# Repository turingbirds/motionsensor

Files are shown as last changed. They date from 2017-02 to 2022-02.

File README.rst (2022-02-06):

motionsensor
============

Microwave doppler effect motion sensor

Features
--------

- USB-powered (150 mA)
- Wakes up host computer on alarm (USB remote wakeup)
- Standalone operation (no PC or USB host required)
- Live velocity (IF) monitoring via USB audio stream to PC
- Automatic gain control
- Data logging
- Driverless operation: tested on Windows XP, Windows 7, Ubuntu GNU/Linux 14.04

..	![Image](https://raw.githubusercontent.com/turingbirds/con-pcb-slot/master/fig1.jpg)

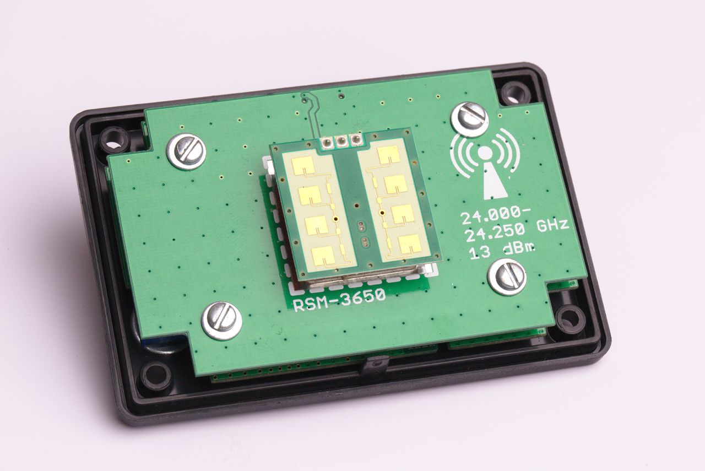
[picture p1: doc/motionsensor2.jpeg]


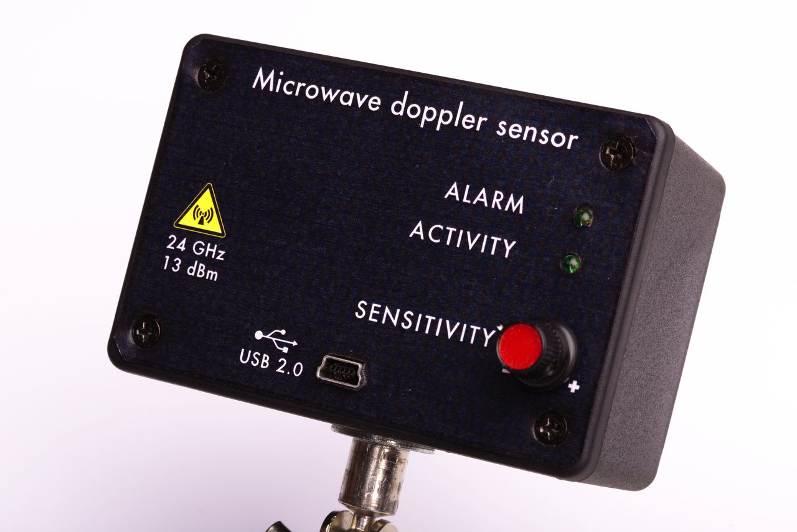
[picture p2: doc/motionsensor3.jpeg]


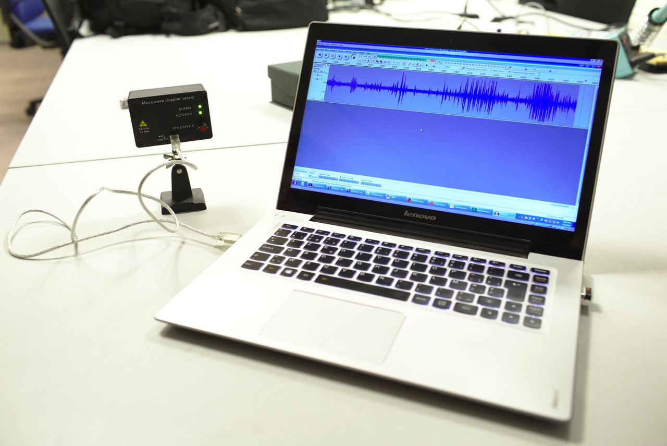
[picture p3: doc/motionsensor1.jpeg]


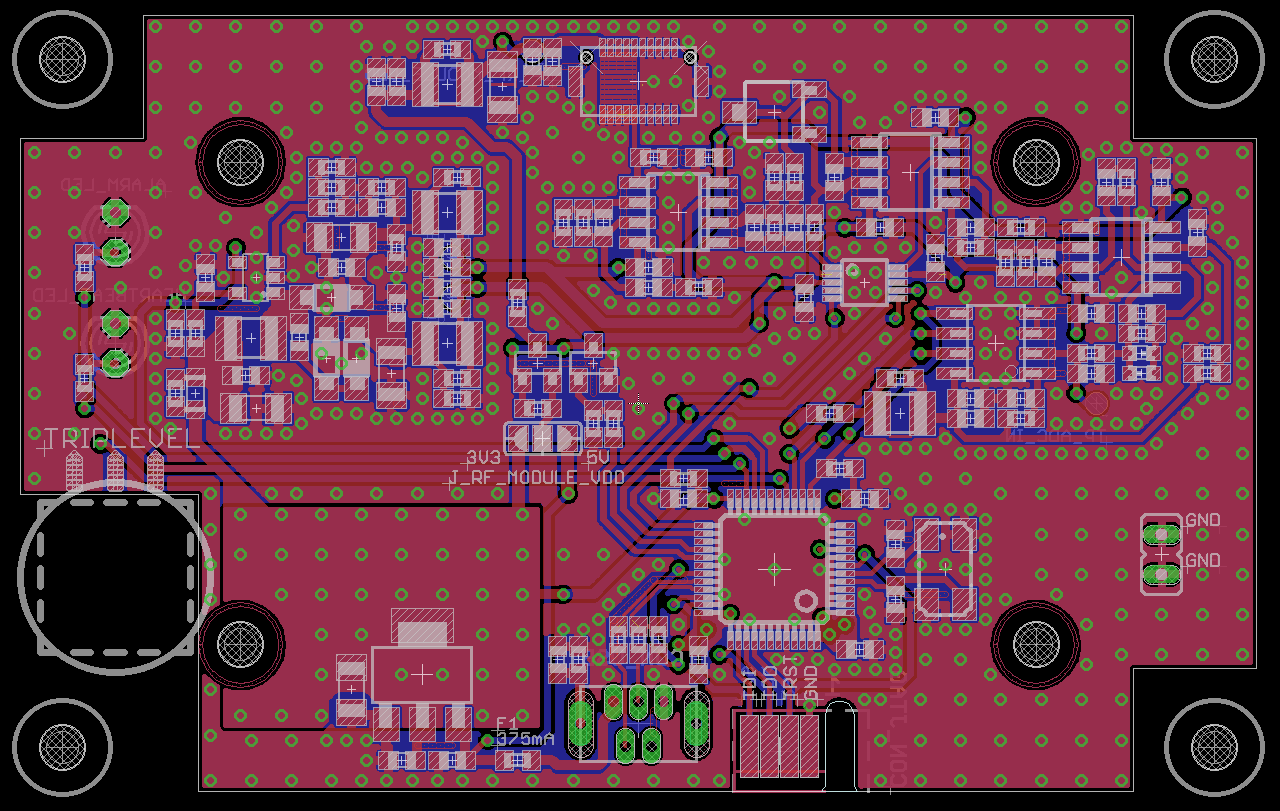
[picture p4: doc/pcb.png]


|

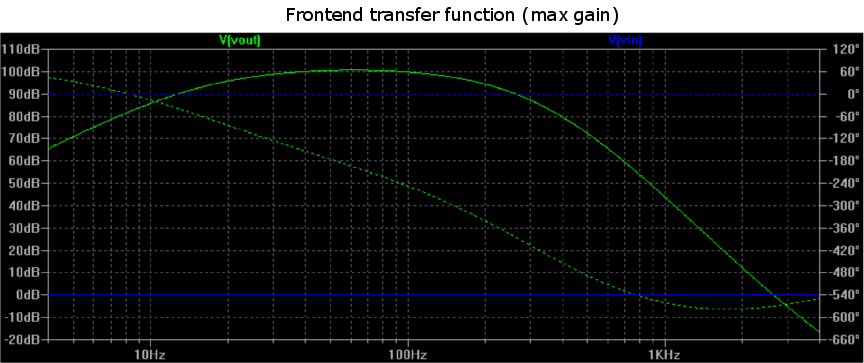
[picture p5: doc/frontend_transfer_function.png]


|

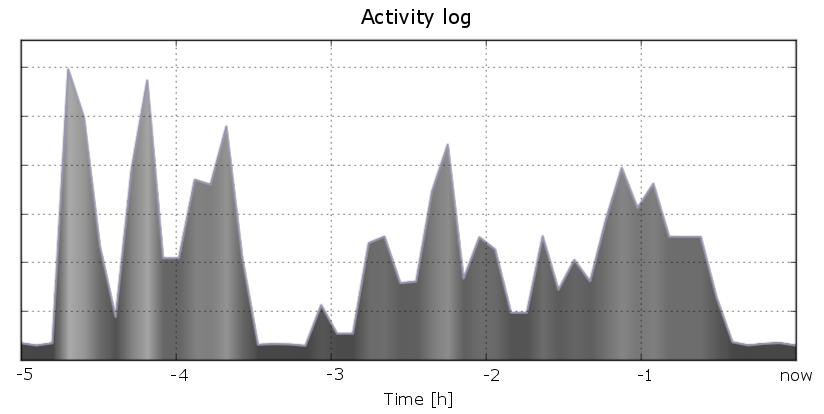
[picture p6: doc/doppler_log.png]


|

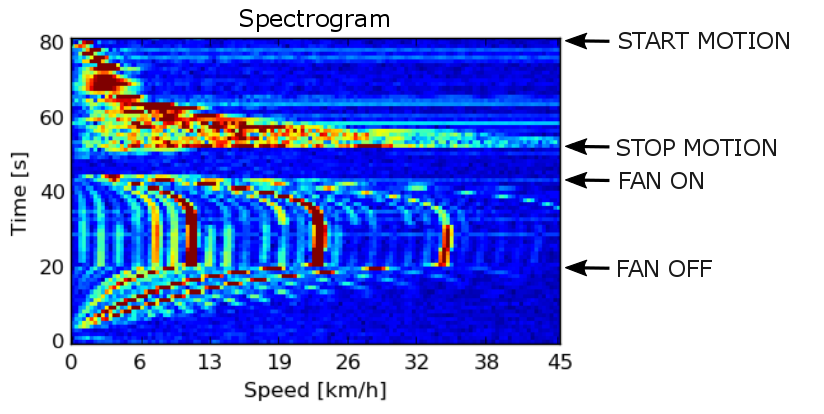
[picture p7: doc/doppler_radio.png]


.. class:: center

All photos thanks to `Dennis van Zuijlekom <https://www.flickr.com/photos/dvanzuijlekom/>`_ at `Hack42 <http://www.hack42.nl>`_!

User guide
==========

Overview
--------

The device is based around a compact radar module. Radar waves penetrate glass and other materials, allowing the device to operate completely hidden from sight, unlike traditional passive infrared (PIR) motion detectors. The principle of operation for motion detection is the doppler effect. The module acts simultaneously as a sender and receiver of radar waves. Part of the emitted waves are reflected in the environment and fall back onto the sensor. If, meanwhile, an object in the environment has a motion component normal to the sensor, a doppler shift will be introduced in the reflected radio waves, proportional to the velocity of the object. The resulting frequency change (between emitted and received frequency) is demodulated by the module and output as a signal in the audio band. The rest of the device amplifies this signal and digitises it for further processing with the microcontroller and (optionally) relay to a connected USB host as an audio stream.

Many radar modules are commercially available for less than $10. This repository contains all the information necessary to build a complete USB/standalone motion detector based on such a module.

USB operation
-------------

The device uses a USB Interface Association Descriptor [1]_ to identify itself as (1) a standard HID-compliant mouse and (2) a standard USB streaming audio device. Only the HID can wake the computer.

Standalone operation
--------------------

The motion sensor does not require a USB host and can operate in standalone mode. For independent operation, supply power (4.5..14 V) via the USB GND and Vcc terminals.

When the alarm is raised, the USB D- line will be driven to +3.3V for at least 10 ms, after which it will return to a floating condition. The output impedance is at least 22 Ω due to the USB series resistor. If this line is used to drive external devices, it is advised to add a modest pull-down resistor (e.g. 4k7).

Host audio
==========

Linux
-----

In case of conflicts, remove interfering kernel drivers:

::

	sudo rmmod snd_usb_audio
	sudo rmmod snd_usbmidi_lib

Set volume levels and such:

::

	alsamixer

Find the motion sensor device:

::

	arecord -l

*Recording from the device:*

::

	arecord -f S16_LE -r 8000 -t raw -v -D hw:1,0 > foo.pcm

*Listening to the device:* This assumes that you are using pulseaudio.

::

	pactl load-module module-loopback latency_msec=1	

Windows XP
----------

*Recording from the device:* native, select "Microwave Doppler Sensor" as audio source

*Listening to the device:* Download "Virtual Audio Cable" [2]_ and use the "Audio Repeater" tool. Lag is at least 50 ms.

Windows 7
---------

*Recording from the device:* native

*Listening to the device:* native. Use "Listen to device" under [taskbar speaker icon] → Recording devices → Microwave Doppler Sensor → Properties → Listen → Listen to this device.

Host power management
=====================

N.B. USB wake needs to be enabled in BIOS

Linux
-----

Suspend using:

::

	pm-suspend

Find device in tree:

::

	grep -r Microwave /sys/devices/pci0000\:00/

In the ``power`` directory of the device, you'll find a file called ``wakeup``. Write "enabled" to this file, e.g.:

::

	echo "enabled" > /sys/devices/pci0000:00/0000:00:14.0/usb2/2-2/power/wakeup

Make sure to enable upstream hubs as well.

N.B. Add the commands in this section to ``/etc/rc.local`` to enable the wake-from-standby feature on boot.

Windows
-------

Enable "Allow device to wake computer from suspend" in the device manager properties of the HID-compatible mouse that is a part of the Microwave Doppler Sensor.

Developer's guide
=================

Frontend
--------

The frontend consists of a high-gain low-noise amplifier chain that is built using three dual op-amp ICs. The maximum theoretical voltage gain is 1.3·10\ :sup:`5` (100 dB). An 8-bit digital potentiometer after the second gain stage is configured as an attenuator and acts as gain control, with a dynamical range of 30 dB. The complete analog front-end is powered by a ±5V bipolar rail that is generated by an on-board boost converter. After amplification and filtering the signal is offered to a 12-bit ADC running at an 8 kHz sampling rate and 3.3 V reference voltage.

Data acquisition and USB communication is performed by an STM32F103 microcontroller. When connected to a USB host, the digital potentiometer setlevel is controlled by the volume setlevel of the device. When the volume is set to 100%, automatic gain control (AGC) is enabled. When not connected to USB, the potentiometer is set to a fixed value so that the frontend gain is high.

N.B. the AGC aliasing filter should be designed for one bit of noise at half the sampling rate, i.e. max. 0.81 mV @ 4 kHz (3.3 V across 12 bits = 0.81 mV/bit)

Firmware notes
--------------

For volume scale (how to map bits to decibels), see e.g. [3]_.

Schematic
---------

`Schematic (.pdf) <doc/motionsensor_schematic.pdf>`_

PCB
---

All discrete components are 0603.

- Dimensions: 78 x 49 mm
- Layers: 4 (two inner ground planes)
- Thickness: 1.2 mm

Enclosure and mounting
----------------------

Vertical cross-section:

::

	----USB/USER INTERFACE----
	- 5 mm plastic inserts (1.0 mm margin)
	- 1.2 mm main PCB
	- 5 mm bus
	- 1.2 mm shield PCB
	- 0.2 mm washer
	----DOPPLER UNIT----
	Total: 12 mm

Screw length: 12 mm
Screw diameter: 2.5 mm

N.B. Doppler module is <7 mm

Bill of materials
-----------------

`Bill of materials (.csv) <doc/bill_of_materials.csv>`_

References
==========

.. [1] USB Complete Fourth Edition: The Developer's Guide (4th edition). Jan Axelson, publisher: Lakeview Research. June 1, 2009
.. [2] `Virtual Audio Cable \<http://software.muzychenko.net/eng/vac.htm\> <http://software.muzychenko.net/eng/vac.htm>`_
.. [3] `USB audio device volume scale \<https://msdn.microsoft.com/en-us/library/windows/hardware/ff537309\> <https://msdn.microsoft.com/en-us/library/windows/hardware/ff537309(v=vs.85).aspx>`_

License
=======

`Open source hardware <https://www.oshwa.org/>`_ is hardware for which the design is made publicly available, so that anyone can study, modify, distribute, make, and sell the design or hardware based on that design, subject to the following license conditions.

Hardware licensed under the *CERN Open Hardware Licence Version 2 - Weakly Reciprocal,* a copy of which is included in this repository at `cern_ohl_w_v2.txt <https://github.com/turingbirds/motionsensor/blob/master/cern_ohl_w_v2.txt>`_.

Software licensed under the *Apache License 2.0,* a copy of which is included at `apache_license_2.0.txt <https://github.com/turingbirds/motionsensor/blob/master/apache_license_2.0.txt>`_.

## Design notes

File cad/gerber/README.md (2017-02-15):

    Top Layer: pcbname.GTL
    Inner Layer: pcbname.GL2(for 4 layer)
    Inner Layer: pcbname.GL3(for 4 layer)
    Bottom Layer: pcbname.GBL
    Solder Mask Top: pcbname.GTS
    Solder Mask Bottom: pcbname.GBS
    Silk Top: pcbname.GTO
    Silk Bottom: pcbname.GBO
    Solder paste top: pcbname.GTP
    Solder paste bottom: pcbname.GBP
    Drill Drawing: pcbname.TXT
    Board Outline + milling (important for USB connector slots): pcbname.GML/GKO

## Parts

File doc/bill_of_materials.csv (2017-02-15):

Qty | Identifier | Description | Value | Package | Mouser #
 |  | RESISTOR | NOT INSTALLED | 0603
2 | R38, R44 | RESISTOR | 0 | 0603
3 | R7, R36, R49 | RESISTOR | 10 | 0603
2 | R27, R29 | RESISTOR | 22 | 0603
7 | R8, R23, R28, R30, R32, R35, R47 | RESISTOR | 100 | 0603
2 | R10, R13 | RESISTOR | 1k | 0603
7 | R5, R31, R33, R34, R43, R45, R48 | RESISTOR | 1k5 | 0603
13 | R1, R2, R3, R4, R11, R14, R15, R17, R20, R24, R26, R37, R40 | RESISTOR | 10k | 0603
1 | R41 | RESISTOR | 3k3 | 0603
1 | R39 | RESISTOR | 47k | 0603
2 | R18, R22 | RESISTOR | 100k | 0603
 | C5 | CAPACITOR | NOT INSTALLED | 0603
2 | C18, C19 | CAPACITOR | 22p | 0603
1 | C36 | CAPACITOR | 470p | 0603
3 | C11, C12, C13, | CAPACITOR | 4n7 | 0603
27 | C9, C10, C14, C16, C17, C20, C21, C22, C24, C25, C26, C27, C28, C29, C31, C33, C34, C35, C37, C38, C42, C43, C46, C47, C48, C50, C51 | CAPACITOR | 47n | 0603
5 | C5, C6, C44, C45, C52 | CAPACITOR | 470n | 0603
3 | C7, C8, C15, | CAPACITOR | 1u | 0603
4 | C23, C30, C39, C40 | CAPACITOR | 10u | 1206 | 581-TCJA106M16R200
5 | L1 | INDUCTOR | 47u/11MHz/2.5R/35mA | 0603 | 963-LBMF1608T470K
1 | L2 | INDUCTOR | 47u/11MHz/2.14R/330mA | 1210 | 815-AISC-1210H-470K
2 | ALARM_LED, HEARTBEAT_LED | LED | GREEN THROUGH-HOLE | 3 mm
2 | D2, D4 | LED | INFRARED 1.6 V | 0603 | 604-APT1608F3C
3 | D5, D6, D7 | DIODE | MBR0520 | SOD-123 | 512-MBR0520L
1 | Q1 | N-CHANNEL MOSFET | BF170 | SOT-23
1 | Q2 | P-CHANNEL MOSFET | NDS0605 | SOT-23
1 | IC1 | IC | AD5290-10k | MSOP-10 | 584-AD5290YRMZ10
1 | U$1 | IC | LM27313 | TSOP-5 | 926-LM27313XMF/NOPB
2 | IC2, IC3 | IC | LM324D | SOIC-14 | 595-LM324ADR
1 | IC5 | IC | LM1117 | SOT-232 | 926-LM1117MPX3.3NOPB
1 | IC4 | IC | STM32F103 | LQFP-48 | 511-STM32F103CBT6
1 | F1 | FUSE | 375mA | 0603 | 581-F0603E0R37FSTR
1 | X1 | XTAL | 8 MHz | CTS406 (5 x 3.2 mm) | 815-ABM3B-8.0-B2-T
1 |  | POTENTIOMETER | 5k LINEAR | PANEL MOUNT | 652-3310P-101-502L | Wiper resistance not critical; can also use 10k
1 |  | POTENTIOMETER KNOB | RED |  | 450-0125 | For black version: 450-0125
1 | R12 | POTENTIOMETER | 100k LINEAR | 3223 SMD
1 | CONN_USB | CONN | USB-MINI | VERTICAL | 538-500075-0517
1 | CONN_SENSOR_ | CONN | HIROSE HEADERS | 20 way, height: 5 mm | 798-DF125020DP0.5V86
1 | CONN_SENSOR | CONN | HIROSE RECEPTACLE | 20 way, height: 5 mm | 798-DF12-20DS-0.5V86
1 |  | ENCLOSURE | HAMMOND | 1591XXLSBK (2.4 x 2.2 x 1.4 inch) | 546-1591XXLSBK |  | 546-1591XXLSBK
4 |  | STANDOFFS | M2.5; 5 mm |  | 761-M0504-25-AL
4 |  | SCREWS | M2.5; 12 mm |  | 534-29304
4 |  | WASHERS | M2.5

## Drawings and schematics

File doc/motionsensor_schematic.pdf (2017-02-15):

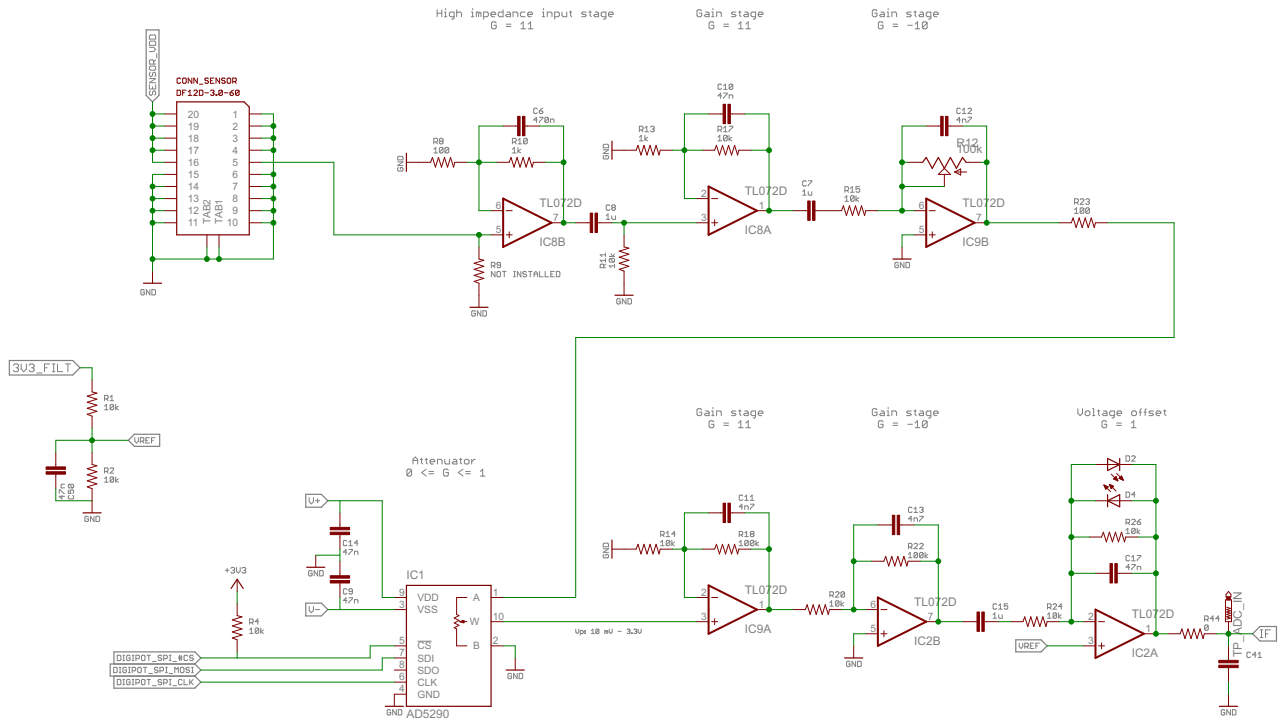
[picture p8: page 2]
100k ¹²³456789 11; TAB¹ TAB²; VDD 9; VSS 3; GND 4; SDI 7; SDO 8; 2 CLK 6; TP_ADC_IN R12

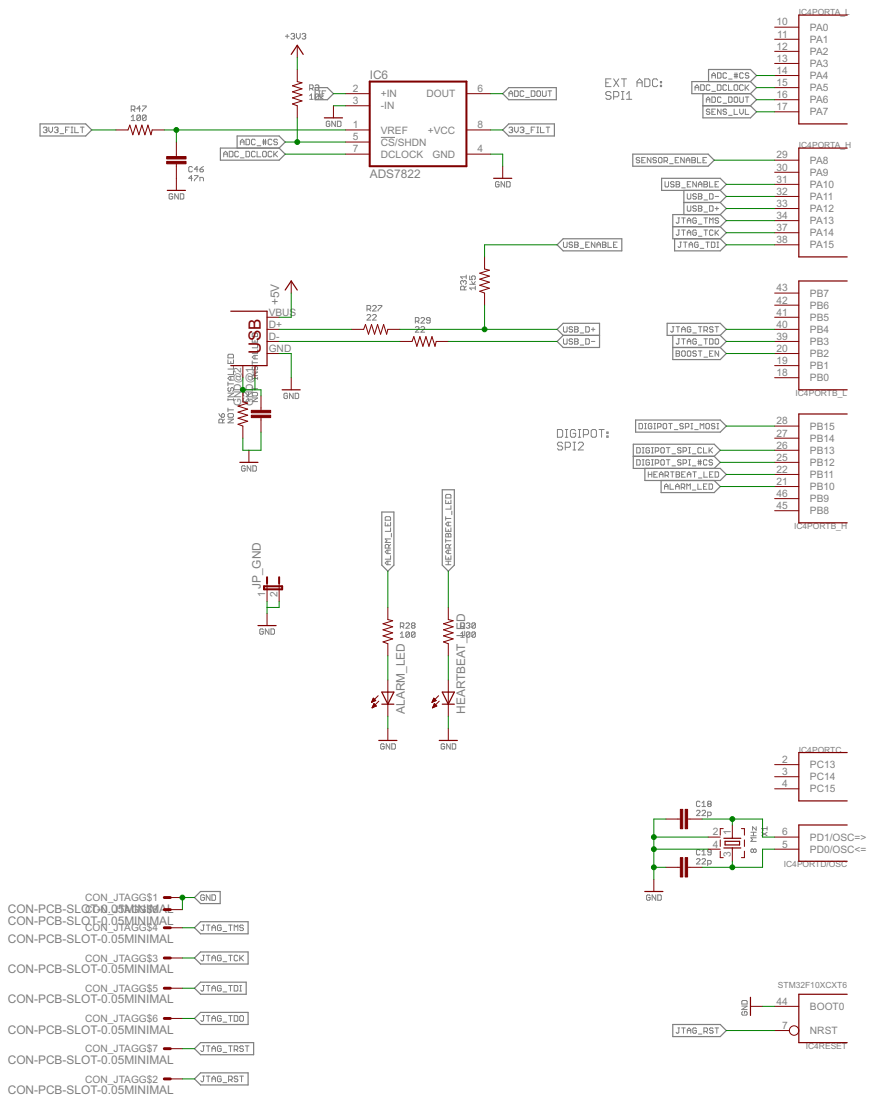
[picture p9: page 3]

+5V ADS7822 CON-PCB-SLOT-0.05MINIMAL CON-PCB-SLOT-0.05MINIMAL CON-PCB-SLOT-0.05MINIMAL CON-PCB-SLOT-0.05MINIMAL CON-PCB-SLOT-0.05MINIMAL CON-PCB-SLOT-0.05MINIMAL CON-PCB-SLOT-0.05MINIMAL CON-PCB-SLOT-0.05MINIMAL PA0 10 PA1 11 PA2 12 PA3 13 PA4 14 PA5 15 PA6 16 PA7 17 IC4PORTA_L PA8 29 PA9 30 PA10 31 PA11 32 PA12 33 PA13 34 PA14 37 PA15 38 IC4PORTA_H PB0 18 PB1 19 PB2 20 PB3 39 PB4 40 PB5 41 PB6 42 PB7 43 IC4PORTB_L PB8 45 PB9 46 PB10 21 PB11 22 PB12 25 PB13 26 PB14 27 PB15 28 IC4PORTB_H PC13 2 PC14 3 PC15 4 IC4PORTC PD0/OSC<= 5 PD1/OSC=> 6IC4PORTD/OSC NRST 7 BOOT0 44STM32F10XCXT6 IC4RESET 3 1 42 ALARM_LED HEARTBEAT_LED D+D- VBUS GND GND@1 GND@2 IC6+IN 2 -IN 3 VREF 1 DCLOCK 7 CS/SHDN 5 DOUT 6 +VCC 8 GND 4 CON_JTAGG$1 CON_JTAGG$8 CON_JTAGG$2 CON_JTAGG$3 CON_JTAGG$4 CON_JTAGG$5 CON_JTAGG$6 CON_JTAGG$7 JP_GND 12 USB

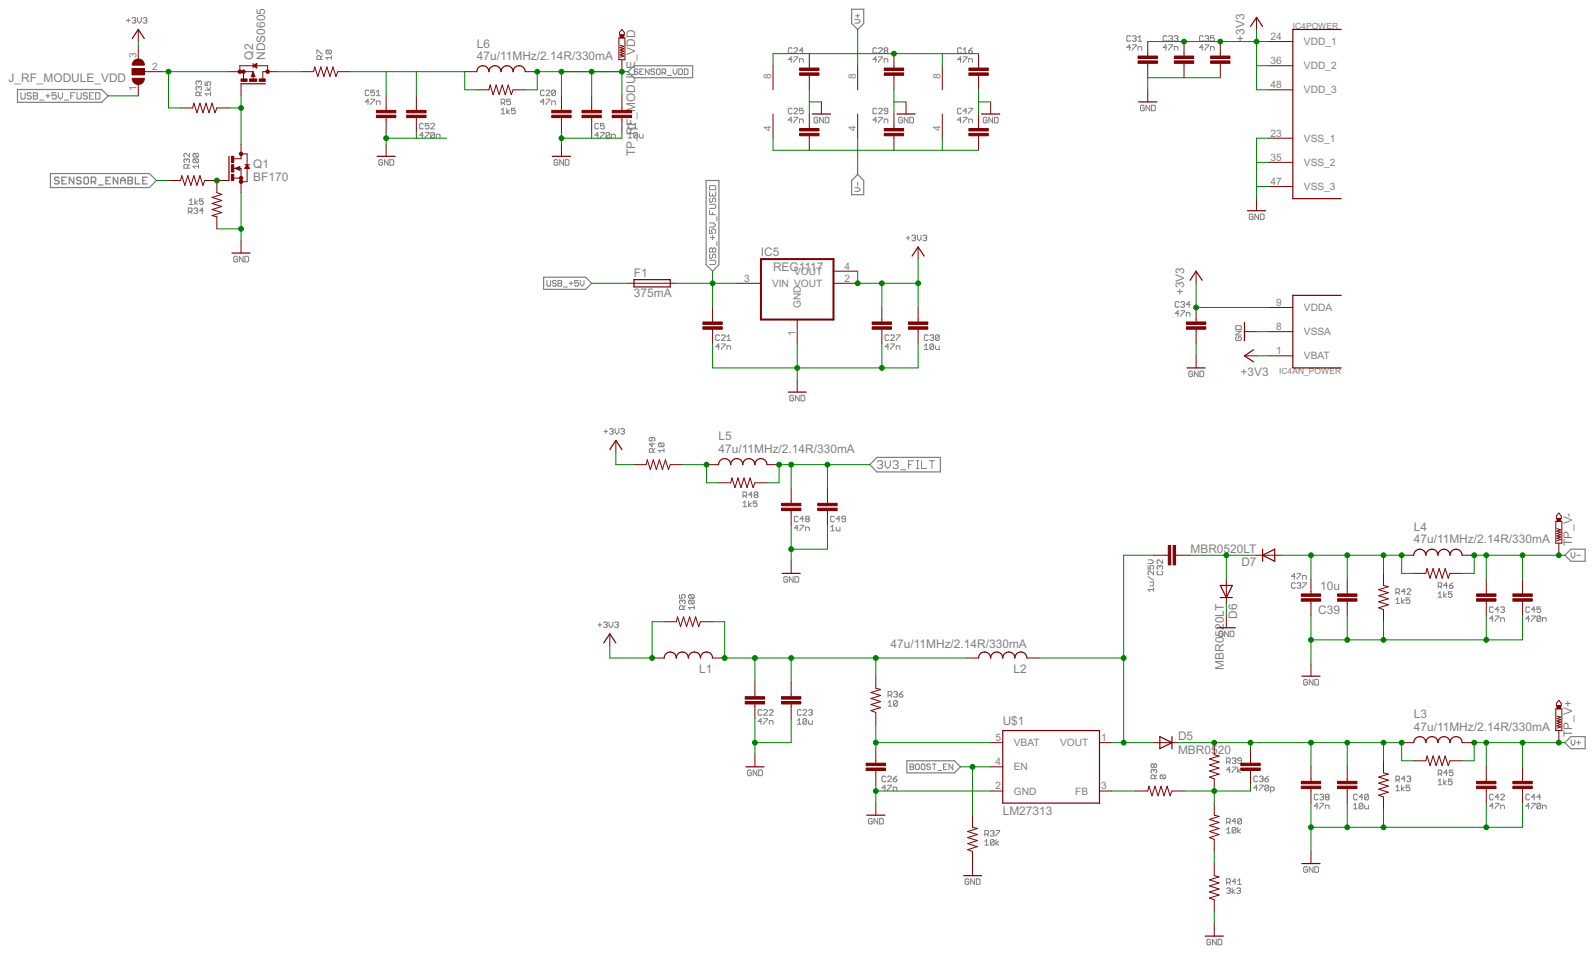
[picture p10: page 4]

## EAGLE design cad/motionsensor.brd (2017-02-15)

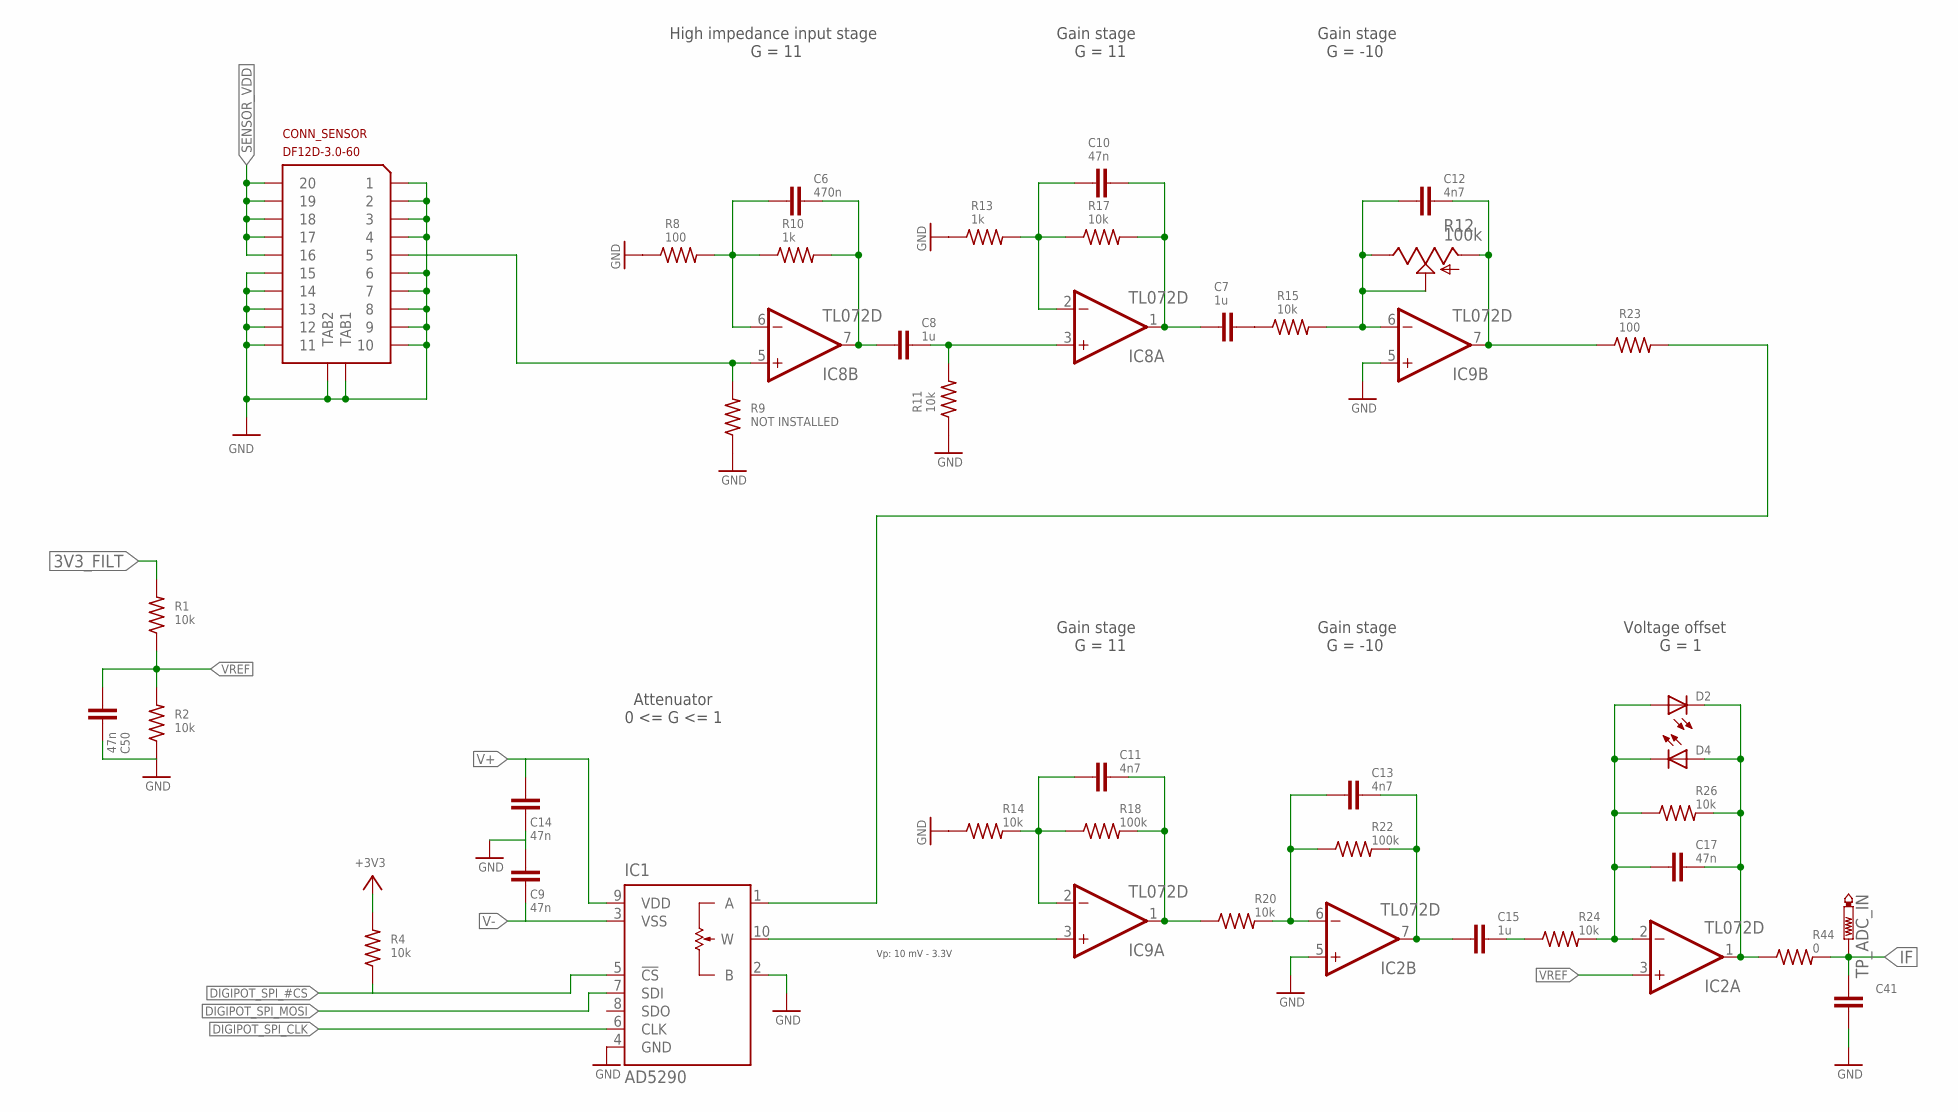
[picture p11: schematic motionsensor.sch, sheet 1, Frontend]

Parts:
C6: 470n; C0603
C7, C8, C15: 1u; C0603
C9, C10, C14, C17, C50: 47n; C0603
C11, C12, C13: 4n7; C0603
C41: C-EUC0603; C0603
CONN_SENSOR: DF12D-3.0-60; DF12-3.0-60
D2, D4: LEDCHIPLED_0603; CHIPLED_0603
IC1: AD5290; MSOP10
IC2, IC8, IC9: TL072D; SO08
R1, R2, R4, R11, R14, R15, R17, R20, R24, R26: 10k; R0603
R8, R23: 100; R0603
R9: NOT INSTALLED; R0603
R10, R13: 1k; R0603
R12: 100k; 3223G
R18, R22: 100k; R0603
R44: 0; R0603
TP_ADC_IN: PTR1B1,27; B1,27

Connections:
3V3_FILT: R1.2; also elsewhere on the board
+3V3: R4.2; also elsewhere on the board
DIGIPOT_SPI_#CS: IC1.5 (!CS), R4.1; also elsewhere on the board
DIGIPOT_SPI_CLK: IC1.6 (CLK); also elsewhere on the board
DIGIPOT_SPI_MOSI: IC1.7 (SDI); also elsewhere on the board
GND: C9.1, C14.2, C41.2, C50.2, CONN_SENSOR.P$1 (1), CONN_SENSOR.P$2 (2), CONN_SENSOR.P$3 (3), CONN_SENSOR.P$4 (4), CONN_SENSOR.P$6 (6), CONN_SENSOR.P$7 (7), CONN_SENSOR.P$8 (8), CONN_SENSOR.P$9 (9), CONN_SENSOR.P$10 (10), CONN_SENSOR.P$11 (11), CONN_SENSOR.P$12 (12), CONN_SENSOR.P$13 (13), CONN_SENSOR.P$14 (14), CONN_SENSOR.P$15 (15), CONN_SENSOR.TAB1, CONN_SENSOR.TAB2, IC1.2 (B), IC1.4 (GND), IC2.5 (+IN), IC9.5 (+IN), R2.1, R8.1, R9.1, R11.1, R13.1, R14.1; also elsewhere on the board
IF: C41.1, R44.2, TP_ADC_IN.TP; also elsewhere on the board
unnamed: C6.1, IC8.6 (-IN), R8.2, R10.1
unnamed: C6.2, C8.1, IC8.7 (OUT), R10.2
unnamed: CONN_SENSOR.P$5 (5), IC8.5 (+IN), R9.2
unnamed: C7.2, R15.1
unnamed: C10.1, IC8.2 (-IN), R13.2, R17.1
unnamed: C7.1, C10.2, IC8.1 (OUT), R17.2
unnamed: C8.2, IC8.3 (+IN), R11.2
unnamed: C12.1, IC9.6 (-IN), R12.2 (S), R12.3 (E), R15.2
unnamed: C12.2, IC9.7 (OUT), R12.1 (A), R23.1
unnamed: IC1.1 (A), R23.2
unnamed: C11.1, IC9.2 (-IN), R14.2, R18.1
unnamed: C11.2, IC9.1 (OUT), R18.2, R20.1
unnamed: C13.1, IC2.6 (-IN), R20.2, R22.1
unnamed: C13.2, C15.1, IC2.7 (OUT), R22.2
unnamed: C15.2, R24.1
unnamed: IC1.10 (W), IC9.3 (+IN)
unnamed: C17.1, D2.A, D4.C, IC2.2 (-IN), R24.2, R26.1
unnamed: C17.2, D2.C, D4.A, IC2.1 (OUT), R26.2, R44.1
SENSOR_VDD: CONN_SENSOR.P$16 (16), CONN_SENSOR.P$17 (17), CONN_SENSOR.P$18 (18), CONN_SENSOR.P$19 (19), CONN_SENSOR.P$20 (20); also elsewhere on the board
V+: C14.1, IC1.9 (VDD); also elsewhere on the board
V-: C9.2, IC1.3 (VSS); also elsewhere on the board
VREF: C50.1, IC2.3 (+IN), R1.1, R2.2

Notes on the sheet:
High impedance input stage
G = 11
Gain stage
G = -10
Voltage offset
G = 1
Attenuator
0 <= G <= 1
Vp: 10 mV - 3.3V

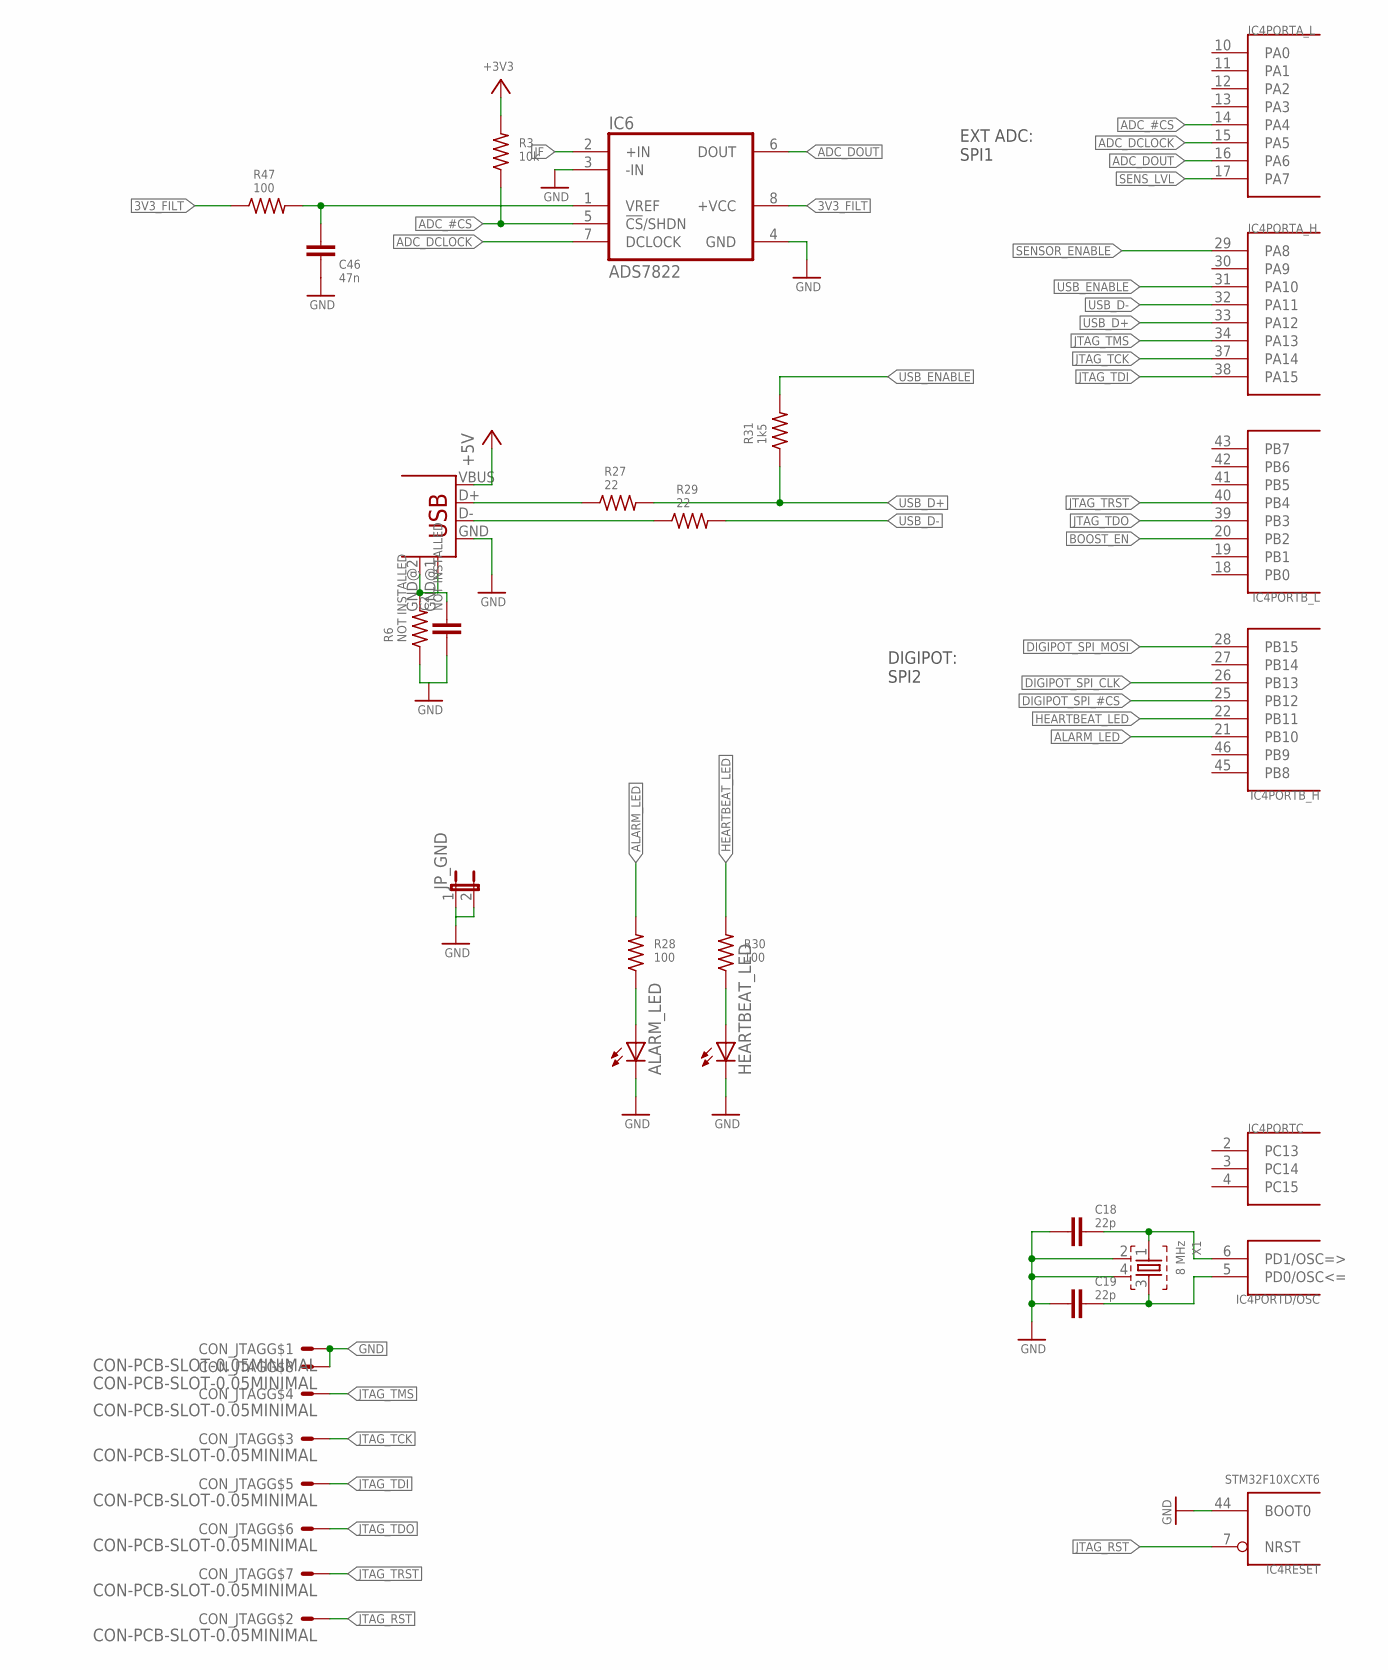
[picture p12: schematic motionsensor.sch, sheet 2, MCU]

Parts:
ALARM_LED: LED3MM
C2: NOT INSTALLED; C0603
C18, C19: 22p; C0603
C46: 47n; C0603
CON_JTAG: CON-PCB-SLOT-0.05MINIMAL; CONN_SLOT_MINIMAL
CON_USB: USB-VERT; USB-MB-V
HEARTBEAT_LED: LED3MM
IC4: STM32F10XCXT6; TQFP48
IC6: ADS7822; SO08
JP_GND: JP1E; JP1
R3: 10k; R0603
R6: NOT INSTALLED; R0603
R27, R29: 22; R0603
R28, R30, R47: 100; R0603
R31: 1k5; R0603
X1: 8 MHz; CTS406

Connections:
3V3_FILT: IC6.8 (+VCC), R47.1; also elsewhere on the board
+3V3: R3.2; also elsewhere on the board
ADC_#CS: IC4.14 (PA4), IC6.5 (!CS!/SHDN), R3.1
ADC_DCLOCK: IC4.15 (PA5), IC6.7 (DCLOCK)
ADC_DOUT: IC4.16 (PA6), IC6.6 (DOUT)
ALARM_LED: IC4.21 (PB10), R28.2
BOOST_EN: IC4.20 (PB2); also elsewhere on the board
DIGIPOT_SPI_#CS: IC4.25 (PB12); also elsewhere on the board
DIGIPOT_SPI_CLK: IC4.26 (PB13); also elsewhere on the board
DIGIPOT_SPI_MOSI: IC4.28 (PB15); also elsewhere on the board
GND: ALARM_LED.K (C), C2.1, C18.1, C19.1, C46.2, CON_JTAG.1, CON_JTAG.8, CON_USB.GND, HEARTBEAT_LED.K (C), IC4.44 (BOOT0), IC6.3 (-IN), IC6.4 (GND), JP_GND.1, JP_GND.2, R6.1, X1.2, X1.4; also elsewhere on the board
HEARTBEAT_LED: IC4.22 (PB11), R30.2
IF: IC6.2 (+IN); also elsewhere on the board
JTAG_RST: CON_JTAG.2, IC4.7 (NRST)
JTAG_TCK: CON_JTAG.3, IC4.37 (PA14)
JTAG_TDI: CON_JTAG.5, IC4.38 (PA15)
JTAG_TDO: CON_JTAG.6, IC4.39 (PB3)
JTAG_TMS: CON_JTAG.4, IC4.34 (PA13)
JTAG_TRST: CON_JTAG.7, IC4.40 (PB4)
unnamed: C2.2, CON_USB.GND@1 (GND), CON_USB.GND@2 (GND), R6.2
unnamed: CON_USB.D+, R27.1
unnamed: C46.1, IC6.1 (VREF), R47.2
unnamed: CON_USB.D-, R29.1
unnamed: C19.2, IC4.5 (PD0/OSC<=), X1.3
unnamed: C18.2, IC4.6 (PD1/OSC=>), X1.1
unnamed: ALARM_LED.A, R28.1
unnamed: HEARTBEAT_LED.A, R30.1
SENSOR_ENABLE: IC4.29 (PA8); also elsewhere on the board
SENS_LVL: IC4.17 (PA7)
USB_+5V: CON_USB.VBUS; also elsewhere on the board
USB_D+: IC4.33 (PA12), R27.2, R31.1
USB_D-: IC4.32 (PA11), R29.2
USB_ENABLE: IC4.31 (PA10), R31.2

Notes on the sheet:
EXT ADC: SPI1
DIGIPOT: SPI2

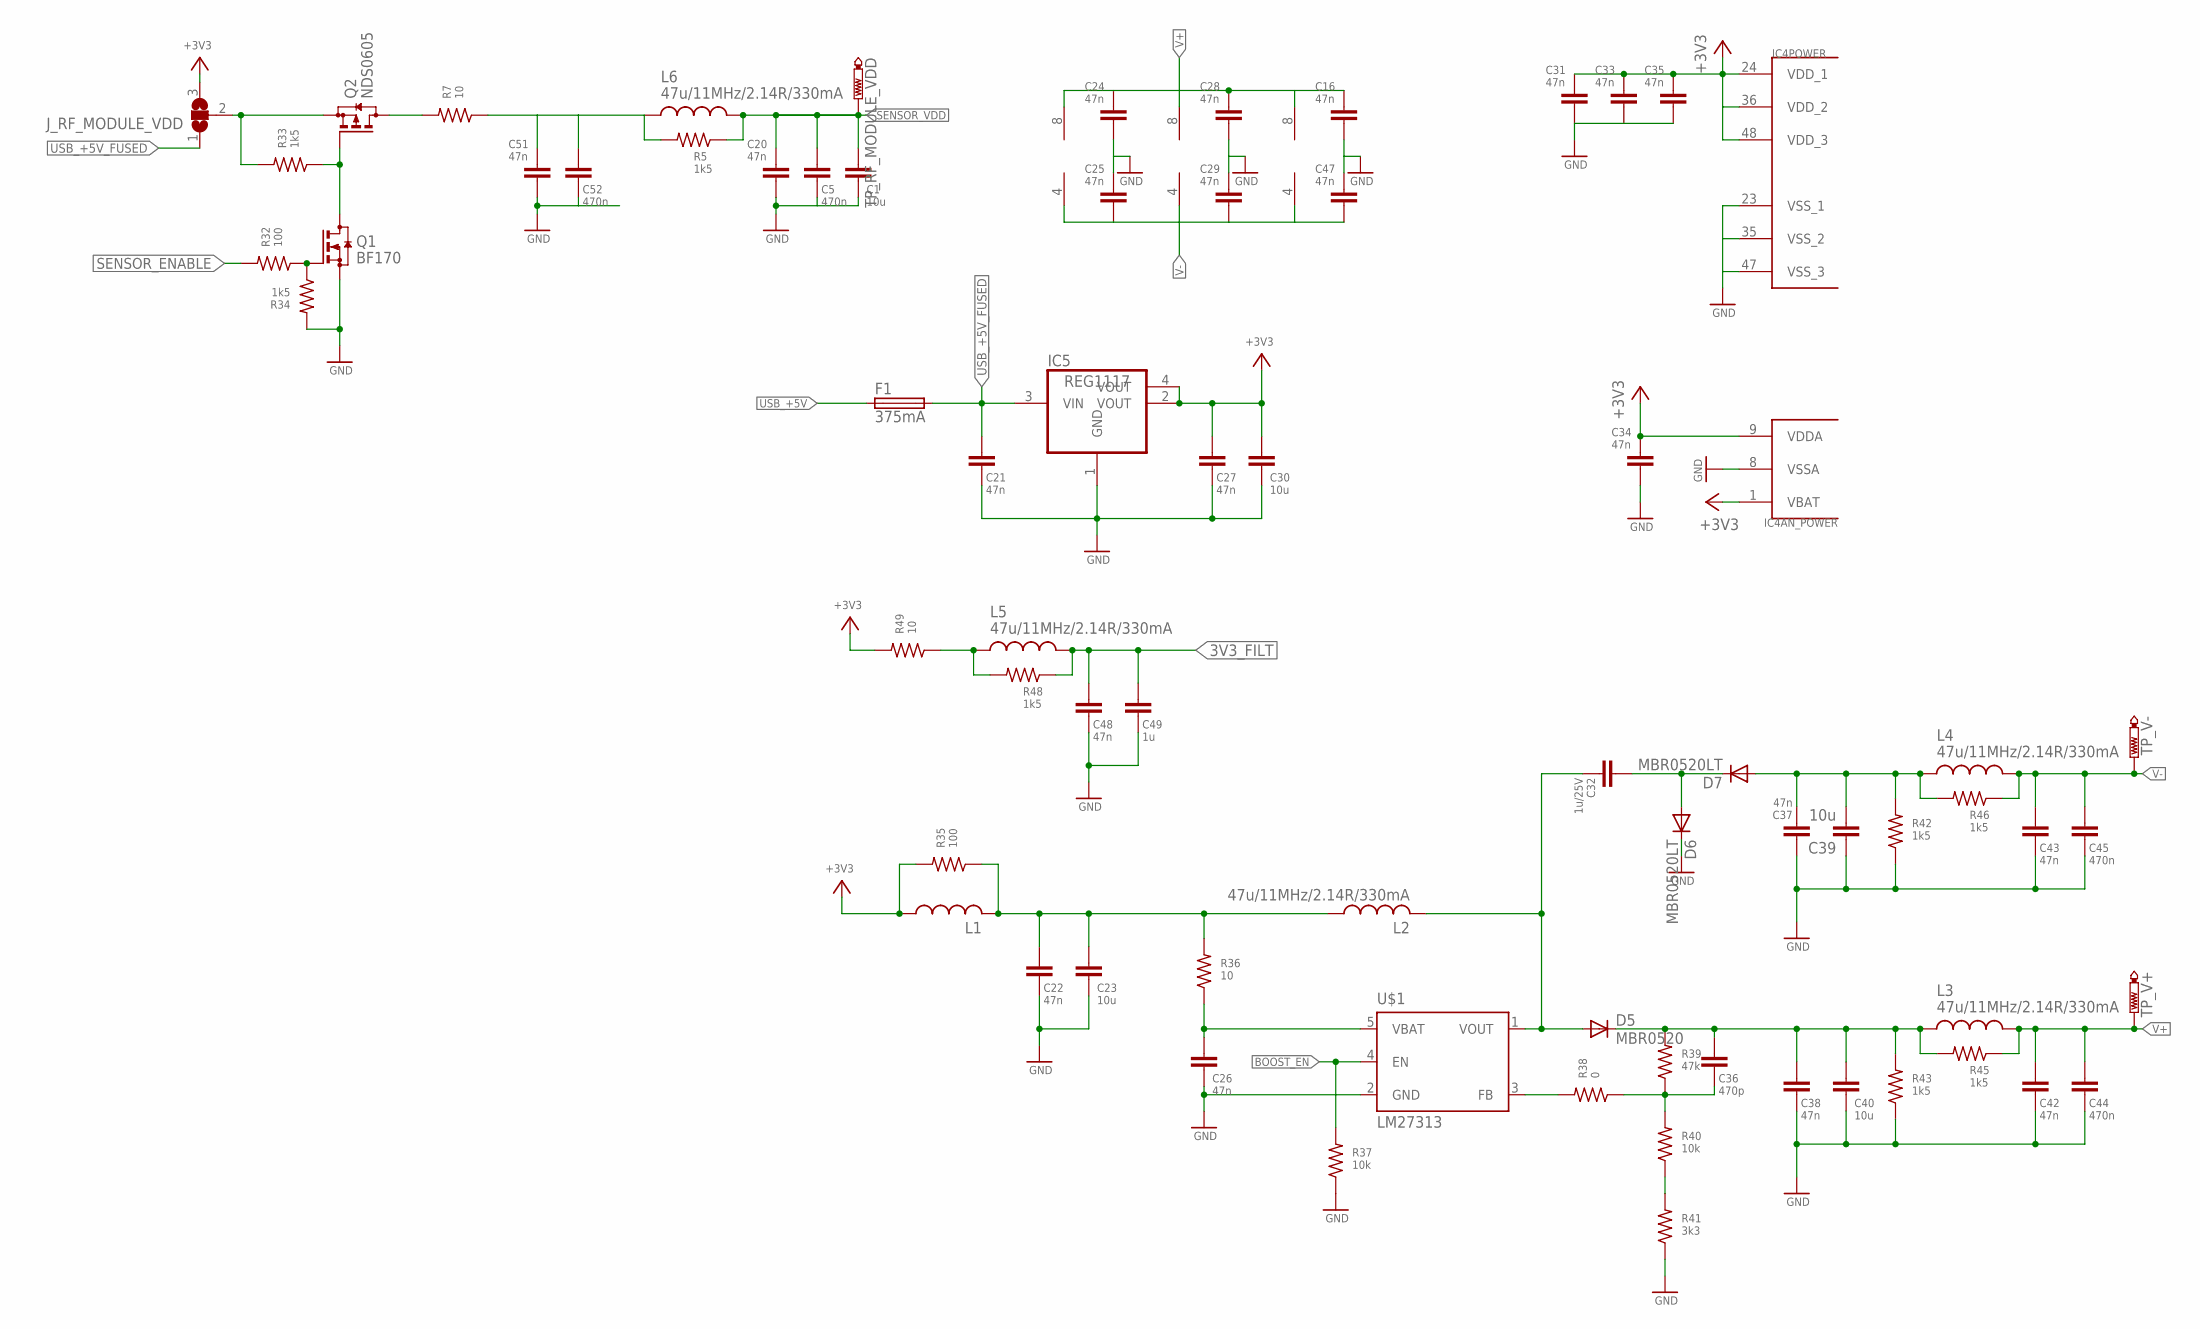
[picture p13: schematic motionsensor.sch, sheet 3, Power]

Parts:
C1, C23, C30, C39, C40: 10u; C1206
C5, C44, C45, C52: 470n; C0603
C16, C20, C21, C22, C24, C25, C27, C28, C29, C31, C33, C34, C35, C37, C38, C42, C43, C47, C48, C51: 47n; C0603
C26: 47n; C1206
C32: 1u/25V; C0603
C36: 470p; C0603
C49: 1u; C0603
D5: MBR0520; SOD123
D6, D7: MBR0520LT; SOD123
F1: 375mA; 0603
IC2, IC8, IC9: TL072D; SO08
IC4: STM32F10XCXT6; TQFP48
IC5: REG1117; SOT223
J_RF_MODULE_VDD: SJ2W; SJ_2
L1: L-USL2012C; L2012C
L2, L3, L4, L5, L6: 47u/11MHz/2.14R/330mA; R1210
Q1: BF170; SOT23
Q2: NDS0605; SOT23
R5, R33, R34, R42, R43, R45, R46, R48: 1k5; R0603
R7, R36, R49: 10; R0603
R32, R35: 100; R0603
R37, R40: 10k; R0603
R38: 0; R0603
R39: 47k; R0603
R41: 3k3; R0603
TP_RF_MODULE_VDD: PTR1B1,27; B1,27
TP_V+: PTR1B1,27; B1,27
TP_V-: PTR1B1,27; B1,27
U$1: LM27313; TSOP5

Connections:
3V3_FILT: C48.1, C49.1, L5.2, R48.1; also elsewhere on the board
+3V3: C27.1, C30.1, C31.2, C33.2, C34.2, C35.2, IC4.1 (VBAT), IC4.9 (VDDA), IC4.24 (VDD_1), IC4.36 (VDD_2), IC4.48 (VDD_3), IC5.2 (VOUT), IC5.4 (VOUT), J_RF_MODULE_VDD.3, L1.1, R35.2, R49.2; also elsewhere on the board
+3V3_FILT: C22.1, C23.1, L1.2, L2.1, R35.1, R36.2
BOOST_EN: R37.2, U$1.4 (EN); also elsewhere on the board
GND: C1.2, C5.2, C16.1, C20.1, C21.2, C22.2, C23.2, C24.1, C25.2, C26.2, C27.2, C28.1, C29.2, C30.2, C31.1, C33.1, C34.1, C35.1, C37.1, C38.2, C39.1, C40.2, C42.2, C43.2, C44.2, C45.2, C47.2, C48.2, C49.2, C51.1, C52.2, D6.C, IC4.8 (VSSA), IC4.23 (VSS_1), IC4.35 (VSS_2), IC4.47 (VSS_3), IC5.1 (GND), Q1.2 (S), R34.2, R37.1, R41.1, R42.1, R43.1, U$1.2 (GND); also elsewhere on the board
unnamed: J_RF_MODULE_VDD.2, Q2.2 (S), R33.2
unnamed: Q2.3 (D), R7.2
unnamed: Q1.1 (G), R32.1, R34.1
unnamed: L5.1, R48.2, R49.1
unnamed: Q1.3 (D), Q2.1 (G), R33.1
unnamed: C32.2, D5.A, L2.2, U$1.1 (VOUT)
unnamed: C26.1, R36.1, U$1.5 (VBAT)
unnamed: C32.1, D6.A, D7.C
unnamed: C36.2, R38.1, R39.1, R40.2
unnamed: R40.1, R41.2
unnamed: R38.2, U$1.3 (FB)
unnamed: C37.2, C39.2, D7.A, L4.1, R42.2, R46.2
unnamed: C36.1, C38.1, C40.1, D5.C, L3.1, R39.2, R43.2, R45.2
SENSOR_ENABLE: R32.2; also elsewhere on the board
SENSOR_VDD: C1.1, C5.1, C20.2, L6.2, R5.1, TP_RF_MODULE_VDD.TP; also elsewhere on the board
SENSOR_VDD1: C51.2, C52.1, L6.1, R5.2, R7.1
USB_+5V: F1.1; also elsewhere on the board
USB_+5V_FUSED: C21.1, F1.2, IC5.3 (VIN), J_RF_MODULE_VDD.1
V+: C16.2, C24.2, C28.2, C42.1, C44.1, IC2.8 (V+), IC8.8 (V+), IC9.8 (V+), L3.2, R45.1, TP_V+.TP; also elsewhere on the board
V-: C25.1, C29.1, C43.1, C45.1, C47.1, IC2.4 (V-), IC8.4 (V-), IC9.4 (V-), L4.2, R46.1, TP_V-.TP; also elsewhere on the board

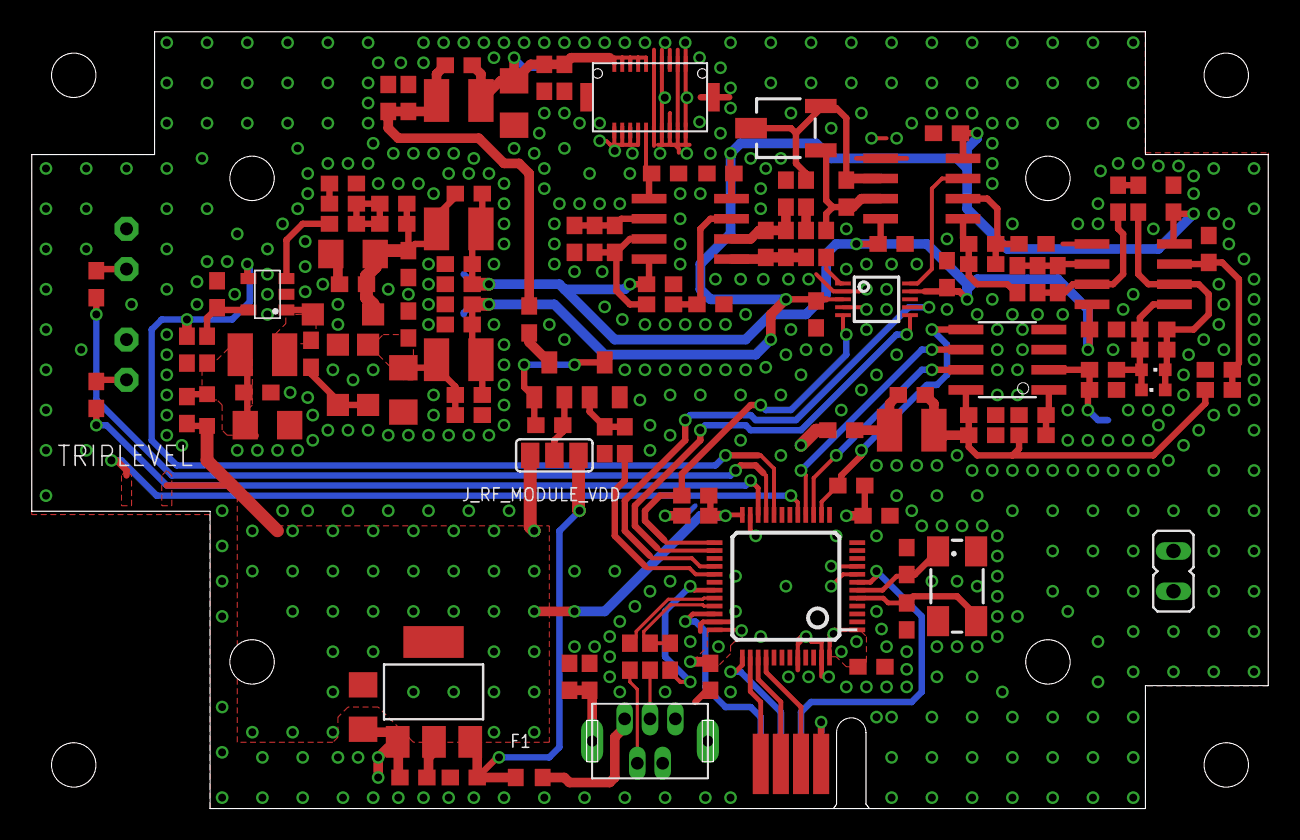
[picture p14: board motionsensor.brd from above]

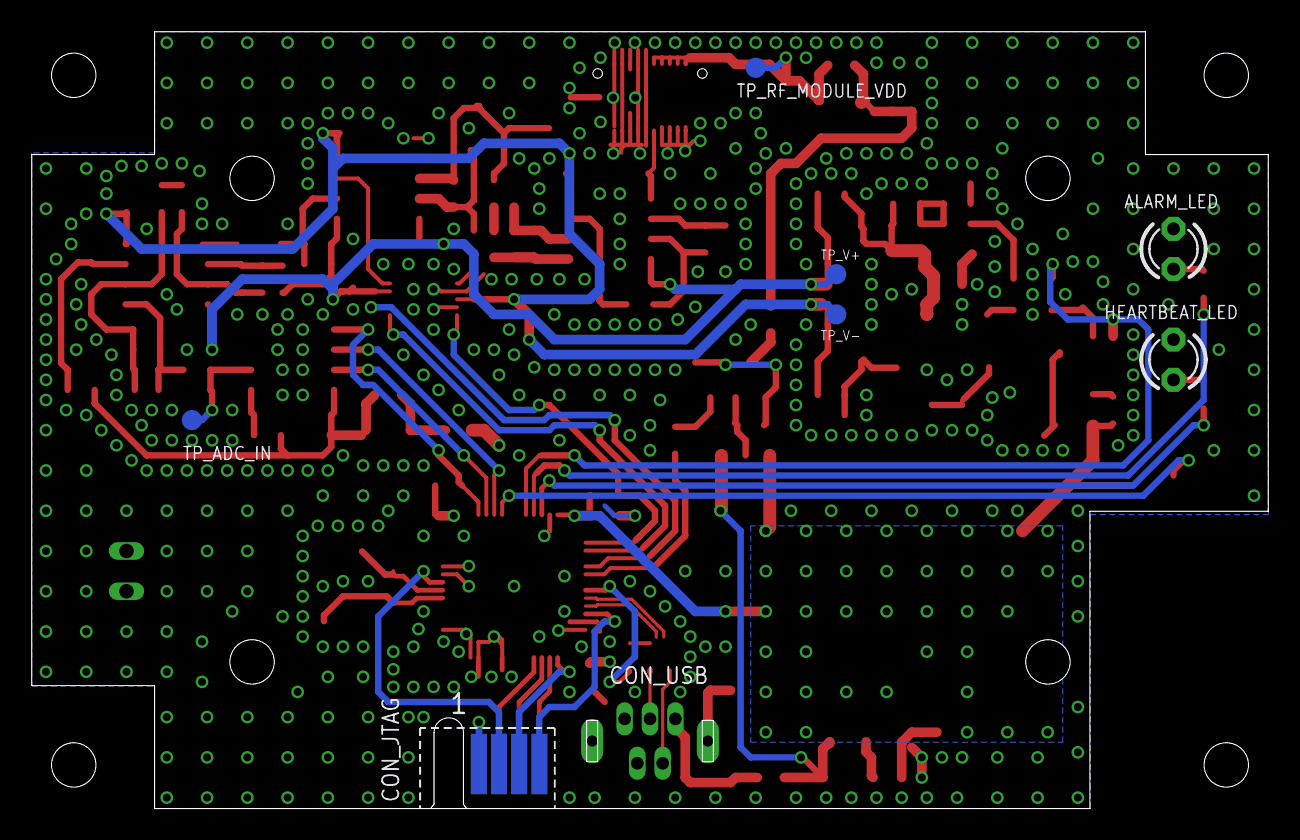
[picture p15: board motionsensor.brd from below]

Board: 4 copper layers, 78.0 x 49.0 mm, 129 parts (8 on the bottom side), 70 nets.

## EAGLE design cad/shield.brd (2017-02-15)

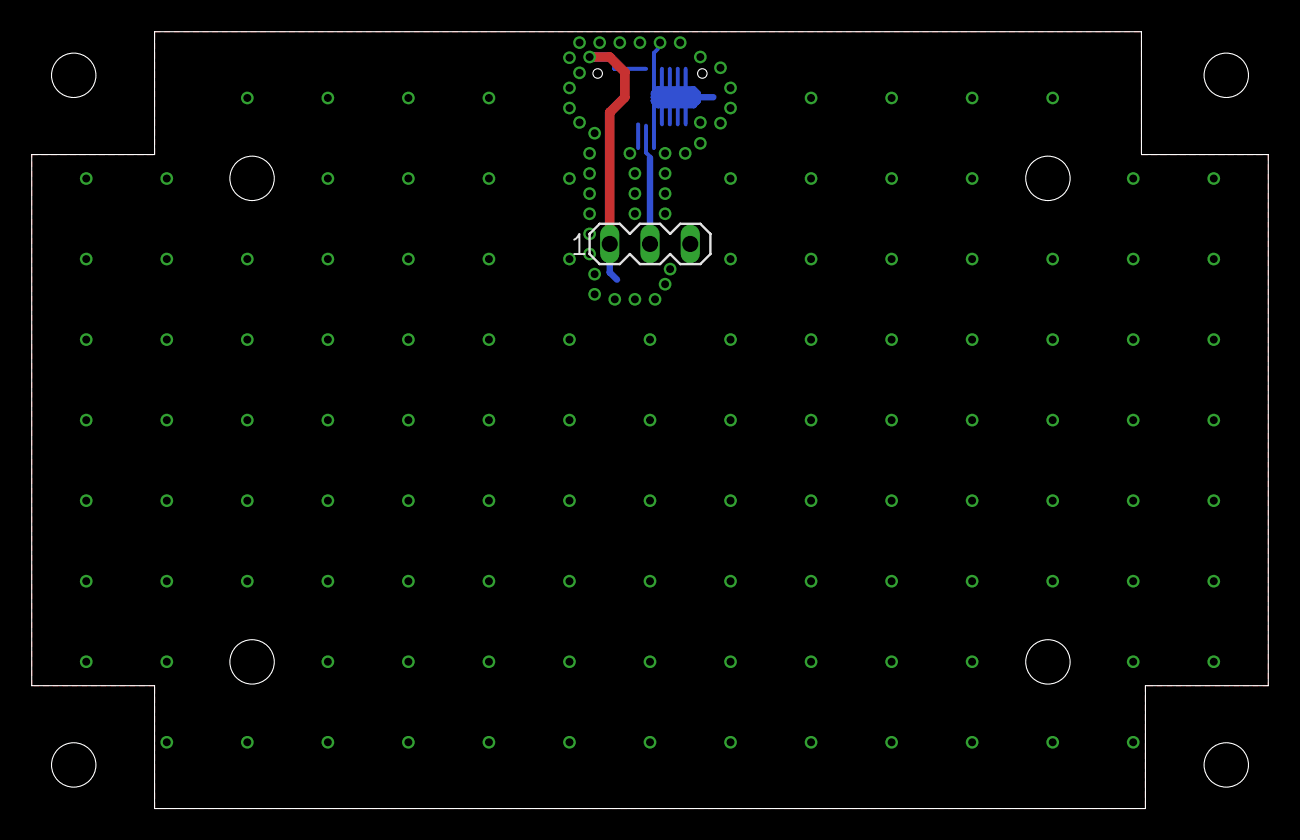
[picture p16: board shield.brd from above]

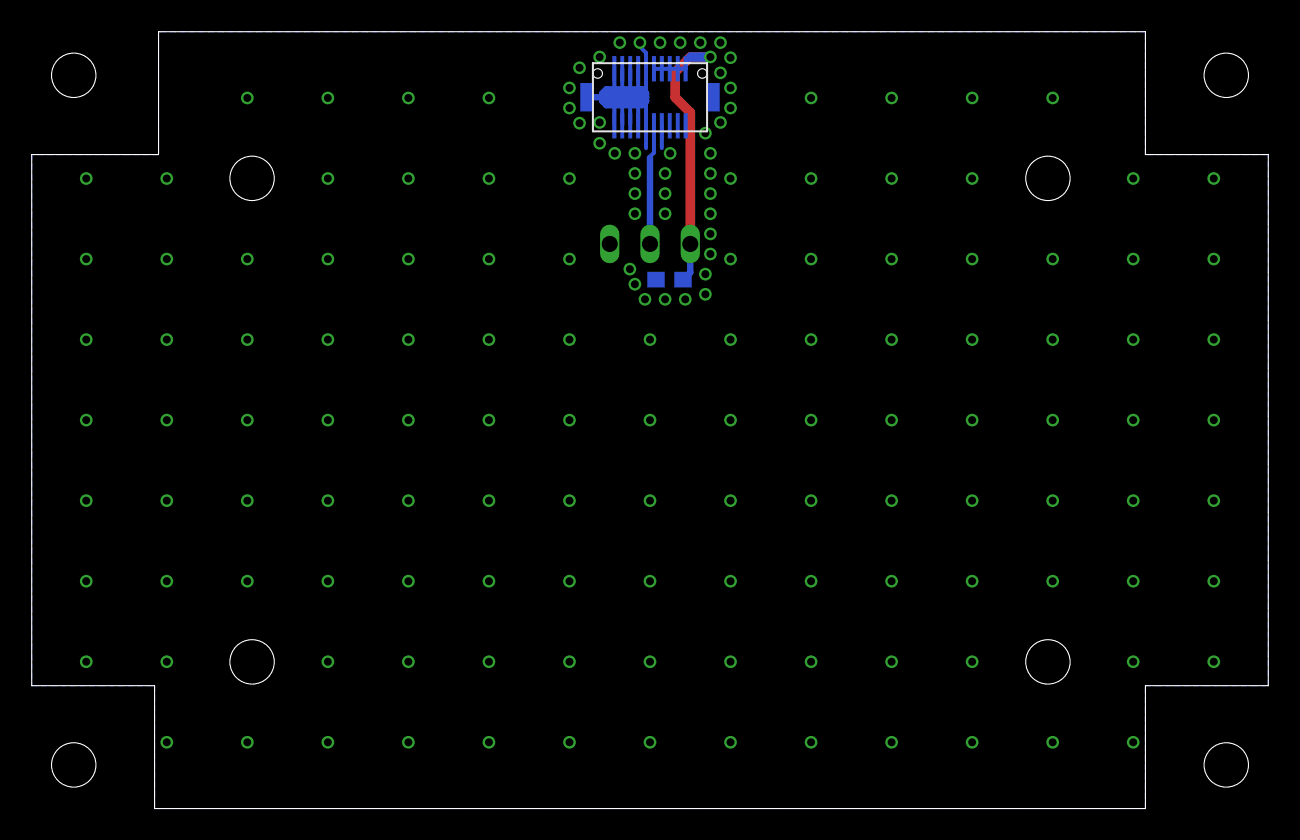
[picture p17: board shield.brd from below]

Board: 4 copper layers, 78.0 x 49.0 mm, 3 parts (2 on the bottom side), 3 nets.

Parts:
C1: 47n; C0603
CONN_SENSOR1: MA03-1
E$1: DF12-3.0-60

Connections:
+3V3: C1.1, CONN_SENSOR1.1, E$1.P$11, E$1.P$12, E$1.P$13, E$1.P$14, E$1.P$15
GND: C1.2, CONN_SENSOR1.3, E$1.P$1, E$1.P$2, E$1.P$3, E$1.P$4, E$1.P$5, E$1.P$7, E$1.P$8, E$1.P$9, E$1.P$10, E$1.P$16, E$1.P$17, E$1.P$18, E$1.P$19, E$1.P$20, E$1.TAB1, E$1.TAB2
S$1: CONN_SENSOR1.2, E$1.P$6

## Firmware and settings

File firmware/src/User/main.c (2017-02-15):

#include "platform.h"


volatile uint16_t brightness;
extern volatile uint16_t wiper_pos;
extern volatile uint8_t throw_alarm;


int main(void) {

	DWT_Init();		// init delays
	platform_init();
	USB_Interrupts_Config();
	Set_USBClock();
	USB_Init();

	DWT_Delay(100000);	// avoid alarm USB wakeup sequence from interfering with USB enumeration
	set_alarm_enable(1);

	while (1) {
		//__WFI();
		__asm("nop");
	}
}

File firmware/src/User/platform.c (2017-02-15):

#include "platform.h"

extern uint32_t SystemCoreClock;


/**
 *	circular buffer for ADC
 *
 * ``adcbuf_idx_write`` points to the next free word.
 * ``adcbuf_idx_read`` points to the next word to be read.
**/

volatile uint16_t adcbuf[ADC_BUFFER_SIZE];
volatile size_t adcbuf_idx_read;
volatile size_t adcbuf_idx_write;


/**
 *	logging
**/

volatile uint8_t log_seq_num;
volatile uint32_t log_integration_window;	// counted in number of samples at 8 kHz
volatile uint32_t log_integration_window_counter;
volatile uint16_t log_signal_level;
volatile uint16_t prev_log_signal_level;

// default integration window = 1 minute
#define DEFAULT_LOG_INTEGRATION_WINDOW 480000


/**
 *	calibration level for ADC
**/

volatile int16_t adc_dc_offset = 0;


/**
 *	alarm
**/

extern volatile uint8_t throw_alarm;
volatile uint8_t alarm_enable;

/* sensitivity potentiometer level */
volatile uint16_t alarm_lvl;

/* instantaneous input level [0..0xFFFF] */
volatile uint16_t input_level;

/* input level tracking on a fast timescale for AGC loop */
volatile uint16_t input_level_tracked_fast;

/* input level tracking on a slow timescale for logging */
volatile uint16_t input_level_tracker_LED;
//volatile uint16_t input_level_tracker_USB;
//volatile uint16_t input_level_tracker_USB_COPY;

/**
 *	current state of the digital potentiometer wiper
**/
volatile uint8_t wiper_pos;


/**
 *
 * LED PWM level
 *
 * generate a triangular waveform /\/\/\/\ in ``lvl``
 *
 * ``blink_period`` sets the frequency of oscillation
 * 0 <= blink_period <= MAX_BLINK_PERIOD
 * ``slowdown`` is for slowing down the ISR rate for rate decay
**/

extern volatile uint8_t blink_period;

extern volatile uint32_t VOLUME_DATA;
volatile uint32_t _VOLUME_DATA;


int logical_right_shift(int x, int n) {
	int size = sizeof(int) * 8;
	return (x >> n) & ~(((0x1 << size) >> n) << 1);
}


void set_alarm_enable(uint8_t _alarm_enable) {
	alarm_enable = _alarm_enable;
}


void init_alarm_led() {
	GPIO_InitTypeDef GPIO_InitStructure;

	RCC_APB2PeriphClockCmd(LED_ALARM_GPIO_CLOCK_DOMAIN, ENABLE);
	GPIO_ResetBits(LED_ALARM_PORT, LED_ALARM_PIN);
	GPIO_InitStructure.GPIO_Pin =  LED_ALARM_PIN;
	GPIO_InitStructure.GPIO_Speed = GPIO_Speed_2MHz;
	GPIO_InitStructure.GPIO_Mode = GPIO_Mode_Out_PP;
	GPIO_Init(LED_ALARM_PORT, &GPIO_InitStructure);

	blink_period = MAX_BLINK_PERIOD;
}


/**
 * 	set wiper position for digital potentiometer
 *
 * 	don't call this too often, as it's slow
**/
void set_wiper(uint8_t _val) {
	//uint8_t _val = ((uint8_t)0xff) - val;
	uint32_t i;
	GPIO_ResetBits(DIGIPOT_SPI_PORT, DIGIPOT_SPI_CS_PIN);
	for (i = 1 << 12; --i; i > 0);
	SPI_I2S_SendData(SPI2, _val);
	while (SPI_I2S_GetFlagStatus(SPI2, SPI_I2S_FLAG_TXE) == RESET);
	for (i = 1 << 12; --i; i > 0);
	GPIO_SetBits(DIGIPOT_SPI_PORT, DIGIPOT_SPI_CS_PIN);
}


void init_adc_spi(void) {
	GPIO_InitTypeDef GPIO_InitStructure;
	SPI_InitTypeDef  SPI_InitStructure;
	NVIC_InitTypeDef NVIC_InitStructure;


	// Configure SPI
	RCC_APB2PeriphClockCmd(RCC_APB2Periph_SPI1, ENABLE);

	SPI_InitStructure.SPI_Direction = SPI_Direction_2Lines_FullDuplex;
	SPI_InitStructure.SPI_Mode = SPI_Mode_Master;
	SPI_InitStructure.SPI_DataSize = SPI_DataSize_16b;
	SPI_InitStructure.SPI_CPOL = SPI_CPOL_Low;
	SPI_InitStructure.SPI_CPHA = SPI_CPHA_1Edge;
	SPI_InitStructure.SPI_NSS = SPI_NSS_Soft;
	SPI_InitStructure.SPI_BaudRatePrescaler = SPI_BaudRatePrescaler_128;
	SPI_InitStructure.SPI_FirstBit = SPI_FirstBit_MSB;
	SPI_Init(SPI1, &SPI_InitStructure);

	SPI_Cmd(SPI1, ENABLE);
	SPI_I2S_ITConfig(SPI1, SPI_I2S_IT_RXNE, ENABLE);

	NVIC_InitStructure.NVIC_IRQChannel = SPI1_IRQn;
	NVIC_InitStructure.NVIC_IRQChannelPreemptionPriority = SPI1_INTR_PRIO;
	NVIC_InitStructure.NVIC_IRQChannelSubPriority = 0;
	NVIC_InitStructure.NVIC_IRQChannelCmd = ENABLE;
	NVIC_Init(&NVIC_InitStructure);

	// configure GPIO
	RCC_APB2PeriphClockCmd(EXTERNAL_ADC_GPIO_CLK_DOMAIN, ENABLE);
	RCC_APB2PeriphClockCmd(RCC_APB2Periph_AFIO, ENABLE);

	// set #CS high (ADC inactive)
	GPIO_SetBits(EXTERNAL_ADC_PORT, EXTERNAL_ADC_CS_PIN);

	GPIO_InitStructure.GPIO_Pin = EXTERNAL_ADC_CS_PIN;
	GPIO_InitStructure.GPIO_Speed = GPIO_Speed_2MHz;
	GPIO_InitStructure.GPIO_Mode = GPIO_Mode_Out_PP;
	GPIO_Init(EXTERNAL_ADC_PORT, &GPIO_InitStructure);

	GPIO_InitStructure.GPIO_Pin = EXTERNAL_ADC_CLK_PIN;
	GPIO_InitStructure.GPIO_Speed = GPIO_Speed_2MHz;
	GPIO_InitStructure.GPIO_Mode = GPIO_Mode_AF_PP;
	GPIO_Init(EXTERNAL_ADC_PORT, &GPIO_InitStructure);

	GPIO_InitStructure.GPIO_Pin = EXTERNAL_ADC_DOUT_PIN;
	GPIO_InitStructure.GPIO_Speed = GPIO_Speed_50MHz;
	GPIO_InitStructure.GPIO_Mode = GPIO_Mode_AF_PP;
	GPIO_Init(EXTERNAL_ADC_PORT, &GPIO_InitStructure);
}


/**
 *	initialize SPI2 interface for digital potentiometer
 *
 *	init GPIO, GPIO_AF and SPI units
**/
void init_digipot_spi(void) {
	GPIO_InitTypeDef GPIO_InitStructure;
	SPI_InitTypeDef  SPI_InitStructure;


	RCC_APB1PeriphClockCmd(RCC_APB1Periph_SPI2, ENABLE);

	SPI_InitStructure.SPI_Direction = SPI_Direction_2Lines_FullDuplex;
	SPI_InitStructure.SPI_Mode = SPI_Mode_Master;
	SPI_InitStructure.SPI_DataSize = SPI_DataSize_16b;
	SPI_InitStructure.SPI_CPOL = SPI_CPOL_Low;
	SPI_InitStructure.SPI_CPHA = SPI_CPHA_1Edge;
	SPI_InitStructure.SPI_NSS = SPI_NSS_Soft;
	SPI_InitStructure.SPI_BaudRatePrescaler = SPI_BaudRatePrescaler_256;
	SPI_InitStructure.SPI_FirstBit = SPI_FirstBit_MSB;
	SPI_Init(SPI2, &SPI_InitStructure);

	//SPI_SSOutputCmd(SPI2, ENABLE);		// Enable NSS (chip select) output
	SPI_CalculateCRC(SPI2, DISABLE);
	SPI_Cmd(SPI2, ENABLE);

	// configure GPIO and GPIO_AF
	RCC_APB2PeriphClockCmd(RCC_APB2Periph_AFIO, ENABLE);
	RCC_APB2PeriphClockCmd(RCC_APB2Periph_GPIOB, ENABLE);

	GPIO_InitStructure.GPIO_Pin = DIGIPOT_SPI_CLK_PIN | DIGIPOT_SPI_MOSI_PIN;
	GPIO_InitStructure.GPIO_Speed = GPIO_Speed_2MHz;
	GPIO_InitStructure.GPIO_Mode = GPIO_Mode_AF_PP;
	GPIO_Init(DIGIPOT_SPI_PORT, &GPIO_InitStructure);

	GPIO_InitStructure.GPIO_Pin = DIGIPOT_SPI_CS_PIN;
	GPIO_InitStructure.GPIO_Speed = GPIO_Speed_2MHz;
	GPIO_InitStructure.GPIO_Mode = GPIO_Mode_Out_PP;
	GPIO_Init(DIGIPOT_SPI_PORT, &GPIO_InitStructure);

	wiper_pos = WIPER_POS_STARTUP;
	set_wiper(wiper_pos);
}
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
